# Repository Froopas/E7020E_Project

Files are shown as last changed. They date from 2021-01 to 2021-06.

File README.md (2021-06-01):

# Project Armory
by Josef Utbult (josutb-7@student.ltu.se) and Anton Johansson (anojoh-7@student.ltu.se)

# Specification
We plan to make a mouse wired mouse of our own design with 2 buttons(left and right), a sensor 
instead of a scroll wheel, a 7 segment display to view your progress and a RGB led strip to give 
you the gaming feeling.

## Parts
To make this we would need:
- A PWM3389DM-T3QU sensor ([datasheet](https://www.pixart.com/products-detail/4/PMW3389DM-T3QU))
- A [STM32F411RE](https://www.st.com/en/microcontrollers-microprocessors/stm32f411re.html#overview) MCU ([Reference Manual](https://www.st.com/resource/en/reference_manual/dm00119316-stm32f411xce-advanced-armbased-32bit-mcus-stmicroelectronics.pdf))
- A 3 digit [7 segment display](https://www.elfa.se/en/segment-led-display-mm-red-tht-everlight-electronics-elt315surwa-s530-a3/p/11068625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) ([datasheet](https://www.elfa.se/Web/Downloads/_t/ds/ELT315SURWA-S530-A3_eng_tds.pdf))
- A [LED strip](https://www.elfa.se/en/ws2812b-led-strip-rgb-5v-18w-1m-seeed-studio-104990014/p/30089752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) ([datasheet](https://www.elfa.se/Web/Downloads/_t/ds/WS2812B_104990014_eng_tds.pdf))
- A [Resistive Linear Sensor](https://www.digikey.com/en/products/detail/spectra-symbol/SP-L-0012-103-1--RH/2175422) ([datasheet](https://media.digikey.com/pdf/Data%20Sheets/Spectra%20Symbol/SP%20Series%20SoftPot.pdf))

## Overall design
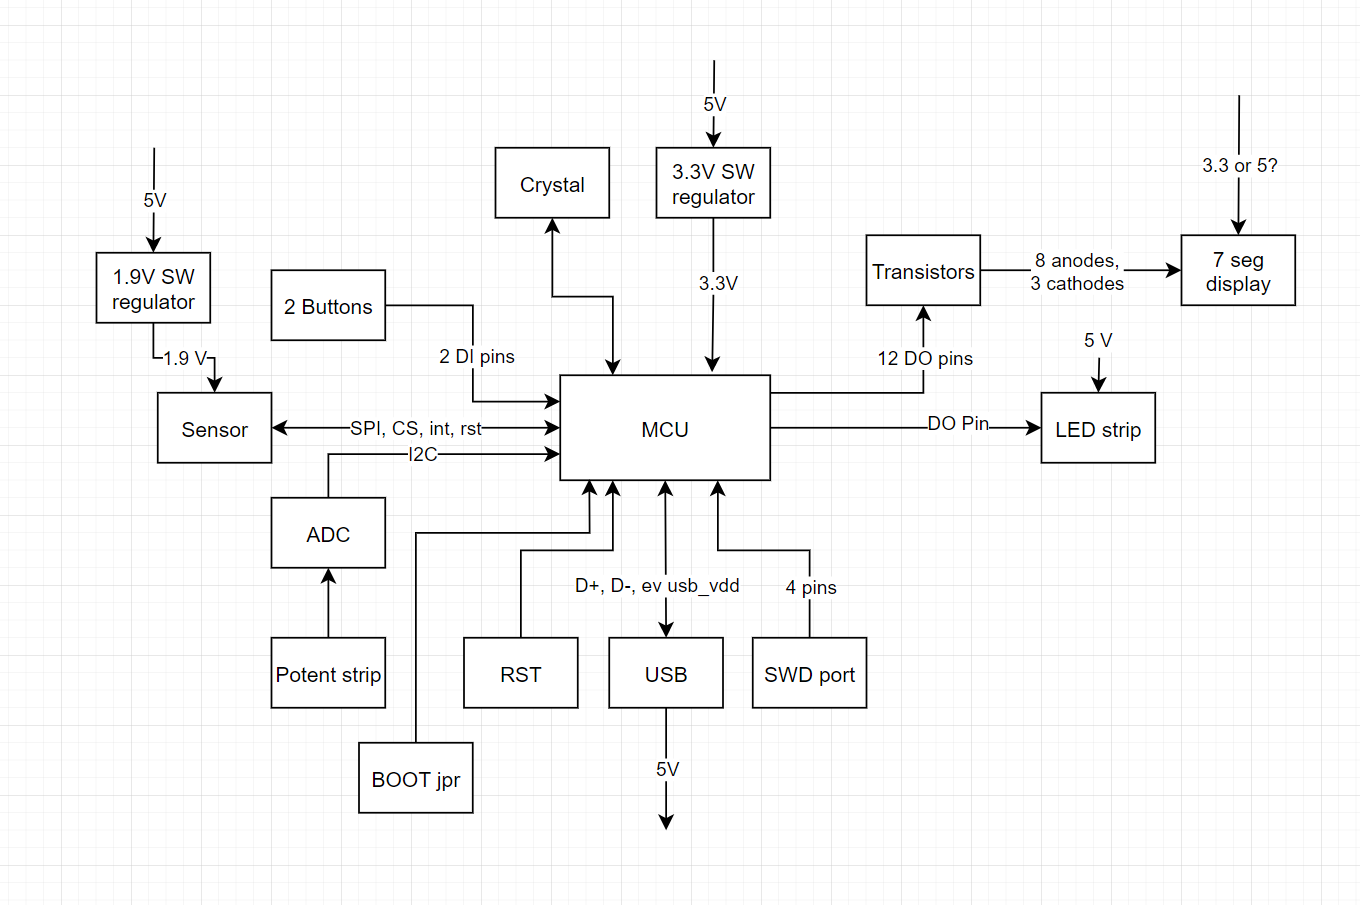
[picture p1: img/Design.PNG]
design Design


## PCB
The PCB is a standard two layer pcb, with the dimentions 40x60 mm.

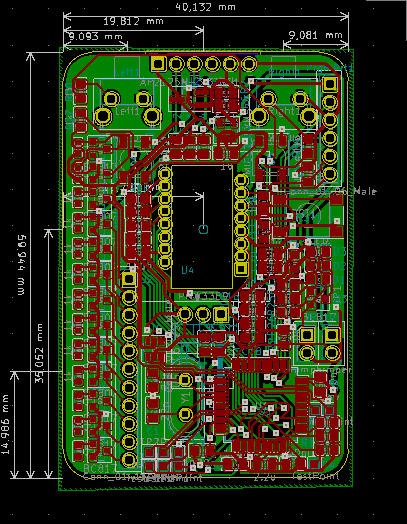
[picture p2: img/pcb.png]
pcb


## Shell
The shell is, at the moment, a 3d render from Fusion 360. It has space for the PCB in the middle 
and some plexi-glass windows to make it more visually pleasing. The buttons on the pcb are 
designed as *vertical* buttons, which means that the mecanic force from the button will have to 
come from the front of the pcb, rather than the top. This enables us to have a shell that is a 
single piece, where some cutout allows the buttons to flex and pivot around where they are joined 
to the rest of the body. The touch strip is placed under the buttons in the middle, and are mounted 
on a seperate piece that is screwed into the rest of the shell.

Shell stuff

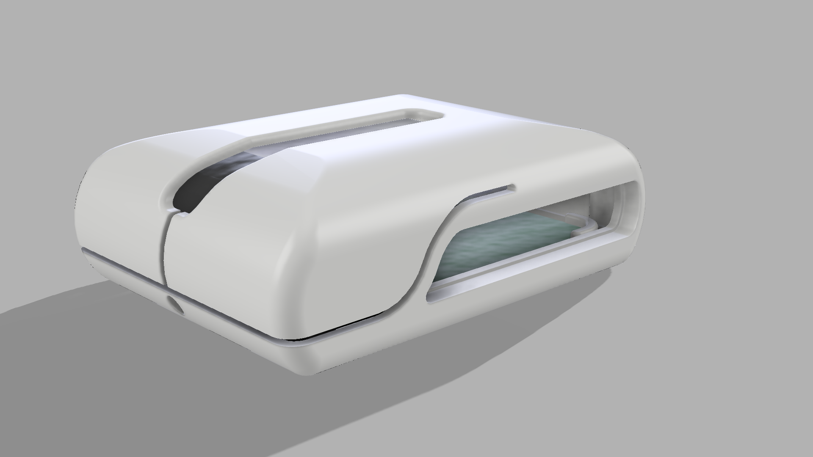
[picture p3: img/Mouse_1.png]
Mouse_1


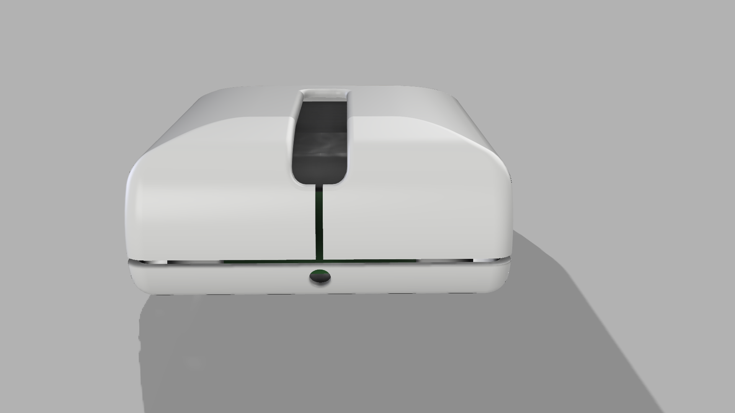
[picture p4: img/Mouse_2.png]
Mouse_2


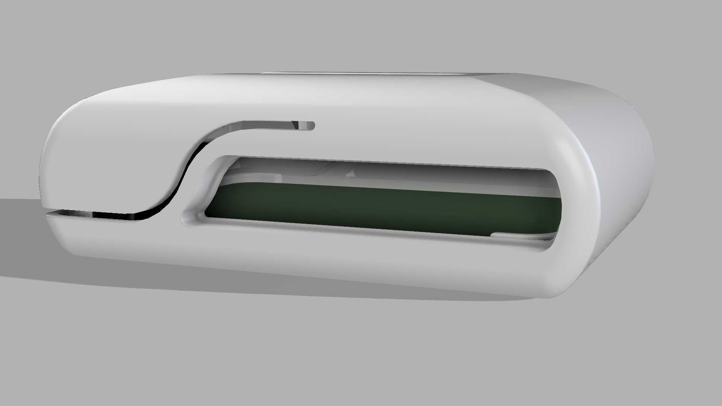
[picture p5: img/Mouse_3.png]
Mouse_3


# Result

As of 26 of March 2021 we have the following result on our project.

## Features

The hardware in place on the mouse is the mcu, the buttons, the PMW sensor and 7 segment 
display. The RGB leds that was supposed to be mounted on the pcb, and the touch sensor was left 
unmounted due to lack of time.

In software we were able to implement RTIC and got the mouse sensor, and the buttons to work with the 
HID protocol. Due to a mismatch in pin selection for the touch strip, the analog pin we chose to connect
the sensor to wasn't compatible with the HAL, which meant we could not get the ADC to work on that pin. 
Therefore, we chose to prioritize other tasks before the touch sensor. And as the RGB leds weren't in 
place we did not test these either.

The first prototype of the shell could fit the pcb and had the sensor working, but it didn't fit the 
display and was not very responsive for the buttons. A second version of this is on the way, but due to 
time constraints this will not be finished for the presentation.

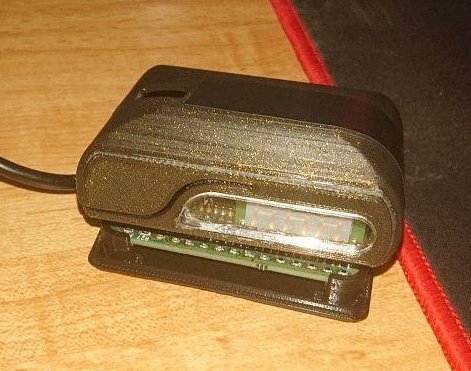
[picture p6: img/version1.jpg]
version1


## Testing

The mouse has been tested on Linux and on Windows. It worked great on Linux, but on Windows we had to 
restart the computer and pull some updates for the mouse to work. The mouse only works on very specific
surfaces, but other than that it is a functional mouse (at best).

## Evaluation

I (Josef) feel that I've could have put in more work on the software side, and less into designing the 
shell. Due to personal problems I had less time to work on it than I would have wanted. 

We feel like we've gotten an acceptable result and that the mouse is good enough for what it is.

## Future goals

We would have liked to implement the following.

* A working touch sensor that supports scrolling and scroll wheel click.

* An ergonomic shell that looks nice and is usable, with easily used mouse buttons.

* Cool led colors.

* Communication from the computer to the mouse to display killcount from CS.

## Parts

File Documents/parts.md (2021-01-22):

# Parts List
## 7 Segment Display
[ELF-511SURWA/S530-A3 - 7](https://www.elfa.se/en/segment-led-display-14-22-mm-red-tht-everlight-electronics-elf-511surwa-s530-a3/p/17506827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) Check how to connect

## Speaker
[KSSG-2308](https://www.elfa.se/en/miniature-loudspeaker-23mm-100mw-8ohm-88db-kingstate-kssg-2308/p/13766343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) Check how to connect

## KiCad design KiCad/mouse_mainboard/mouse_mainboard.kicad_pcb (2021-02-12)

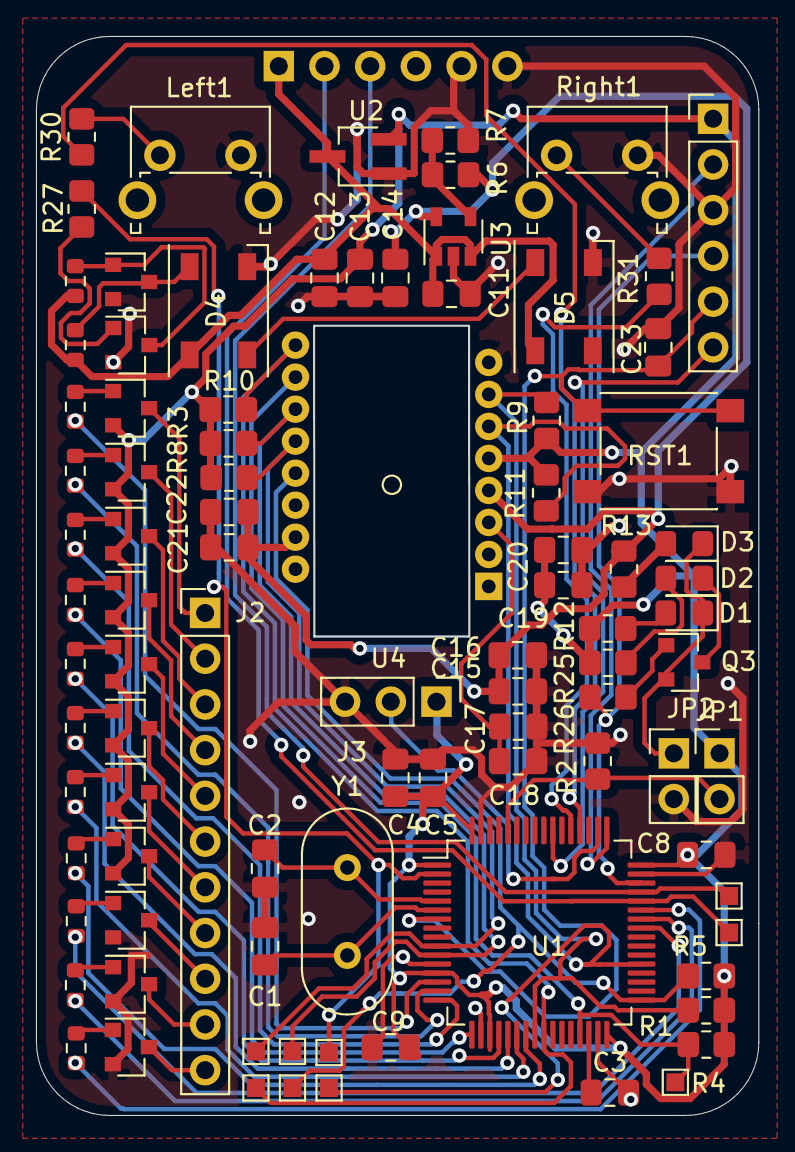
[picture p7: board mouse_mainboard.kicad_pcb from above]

Board: 4 copper layers, 40.1 x 59.9 mm, 93 parts (1 on the bottom side), 72 nets.

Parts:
C1, C2: 47p; C_0805_2012Metric_Pad1.18x1.45mm_HandSolder
C3, C14: 2.2u; C_0805_2012Metric_Pad1.18x1.45mm_HandSolder
C4, C18: 4.7u; C_0805_2012Metric_Pad1.18x1.45mm_HandSolder
C5, C8, C9, C15, C17, C19, C21, C23: 100n; C_0805_2012Metric_Pad1.18x1.45mm_HandSolder
C11, C12, C13: 1u; C_0805_2012Metric_Pad1.18x1.45mm_HandSolder
C16, C20, C22: 10u; C_0805_2012Metric_Pad1.18x1.45mm_HandSolder
D1, D2, D3: LED; LED_0805_2012Metric_Pad1.15x1.40mm_HandSolder
D4, D5: WS2812B; LED_WS2812B_PLCC4_5.0x5.0mm_P3.2mm
J1: USB_OTG; PinHeader_1x06_P2.54mm_Vertical
J2: Conn_01x11_Male; PinHeader_1x11_P2.54mm_Vertical
J3: Conn_01x03_Male; PinHeader_1x03_P2.54mm_Vertical
JP1, JP2: Jumper; PinHeader_1x02_P2.54mm_Vertical
Left1: SW_Push; SW_Tactile_SPST_Angled_PTS645Vx58-2LFS
PrgmPrt1: Conn_01x06_Male; PinHeader_1x06_P2.54mm_Vertical
Q1, Q2, Q4, Q5, Q6, Q8, Q10, Q12: BC807; SOT-23
Q3, Q7, Q9, Q11, Q13, Q14: BC817; SOT-23
R1, R2, R3, R4, R5, R7, R8, R9, R10, R11: 10k; R_0805_2012Metric_Pad1.20x1.40mm_HandSolder
R6: 5.6K; R_0805_2012Metric_Pad1.20x1.40mm_HandSolder
R12, R25: 750R; R_0805_2012Metric_Pad1.20x1.40mm_HandSolder
R13: 50R; R_0805_2012Metric_Pad1.20x1.40mm_HandSolder
R14, R15, R16, R17, R18, R19, R20, R21, R22, R23, R24, R28, R29: 1k; R_0603_1608Metric
R26, R27, R30, R31: 1k; R_0805_2012Metric_Pad1.20x1.40mm_HandSolder
RST1: SW_Push; SW_Push_1P1T_NO_6x6mm_H9.5mm
Right1: SW_Push; SW_Tactile_SPST_Angled_PTS645Vx58-2LFS
TP1, TP2, TP3, TP4, TP5, TP6, TP7, TP8, TP9: TestPoint; TestPoint_Pad_1.0x1.0mm
U1: STM32F411RETx; LQFP-64_10x10mm_P0.5mm
U2: AP2125N-3.3TRG1; SOT-23W_Handsoldering
U3: MIC5235YM5-TR; SOT-23-5
U4: PMW3389; PWM3389DM-T3QU
Y1: Crystal; Crystal_HC49-4H_Vertical

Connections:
+5V: C11.1, C12.1, D4.1, D5.1, J1.1, R28.1, R29.1, U2.3, U3.1, U3.3
GND: C1.2, C2.1, C3.2, C4.2, C5.2, C8.1, C9.1, C11.2, C12.2, C13.2, C14.2, C15.1, C16.1, C17.1, C18.1, C19.1, C20.1, C21.1, C22.1, C23.2, D4.3, D5.3, J1.5, J1.6, J3.3, JP2.2, Left1.2, PrgmPrt1.3, Q7.2, Q9.2, Q11.2, Q13.2, Q14.2, R2.2, R7.1, RST1.2, Right1.2, U1.12, U1.18, U1.31, U1.47, U1.63, U2.1, U3.2, U4.8
unnamed: C1.1, U1.6, Y1.1
unnamed: C2.2, U1.5, Y1.2
unnamed: C3.1, U1.30
unnamed: C17.2, C18.2, U4.3
unnamed: D1.1, D3.1, JP2.1, Q3.2
unnamed: D1.2, R12.2
unnamed: D2.1, Q3.3
unnamed: D2.2, R25.2
unnamed: D3.2, R13.2
unnamed: D4.2, D5.4
unnamed: D4.4, Q14.3, R29.2
unnamed: J2.1, Q12.3
unnamed: J2.2, Q10.3
unnamed: J2.3, Q8.3
unnamed: J2.4, Q6.3
unnamed: J2.5, Q5.3
unnamed: J2.6, Q4.3
unnamed: J2.7, Q2.3
unnamed: J2.8, Q1.3
unnamed: J2.9, Q7.3
unnamed: J2.10, Q9.3
unnamed: J2.11, Q11.3
unnamed: JP1.2, R2.1, U1.60
unnamed: Left1.1, R30.1
unnamed: Q1.1, R24.1
unnamed: Q2.1, R23.1
unnamed: Q3.1, R26.2
unnamed: Q4.1, R22.1
unnamed: Q5.1, R20.1
unnamed: Q6.1, R18.1
unnamed: Q7.1, R17.2
unnamed: Q8.1, R16.1
unnamed: Q9.1, R19.2
unnamed: Q10.1, R15.1
unnamed: Q11.1, R21.2
unnamed: Q12.1, R14.1
unnamed: Q13.1, R27.2
unnamed: Q13.3, Q14.1, R28.2
unnamed: R6.1, R7.2, U3.4
unnamed: R31.1, Right1.1
VDD: C14.1, C15.2, C16.2, C21.2, C22.2, R6.2, R13.1, U3.5, U4.4, U4.15
btn_l: R30.2, U1.52
btn_r: R31.2, U1.53
disp_1: R14.2, U1.14
disp_2: R15.2, U1.15
disp_3: R16.2, U1.16
disp_4: R18.2, U1.17
disp_5: R20.2, U1.20
disp_6: R22.2, U1.21
disp_7: R23.2, U1.22
disp_8: R24.2, U1.23
disp_d1: R17.1, U1.41
disp_d2: R19.1, U1.42
disp_d3: R21.1, U1.43
led_d: R27.1, TP5.1, U1.2
mcu_cap: C4.1, C5.1, C8.2, C9.2, C13.1, C19.2, C20.2, J3.1, JP1.1, PrgmPrt1.1, Q1.2, Q2.2, Q4.2, Q5.2, Q6.2, Q8.2, Q10.2, Q12.2, R1.1, R3.1, R4.1, R5.1, R8.2, R9.2, R10.2, R11.2, R12.1, R25.1, U1.1, U1.13, U1.19, U1.32, U1.48, U1.64, U2.2, U4.5
miso: R8.1, TP2.1, U1.10, U4.12
mosi: R3.2, TP1.1, U1.11, U4.11
ncs: R5.2, TP9.1, U1.33, U4.13
pwm_gpo: R11.1, TP4.1, U1.37, U4.6
pwm_int: R10.1, TP3.1, U1.25, U4.9
pwm_rst: R1.2, R9.1, U1.24, U4.7
sclk: R4.2, TP8.1, U1.29, U4.10
strip_out: J3.2, U1.50
sw_clk: PrgmPrt1.2, U1.49
sw_io: PrgmPrt1.4, R26.1, U1.46
sw_o: PrgmPrt1.6, U1.55
sw_rst: C23.1, PrgmPrt1.5, RST1.1, U1.7
usb_d+: J1.3, TP7.1, U1.45
usb_d-: J1.2, TP6.1, U1.44

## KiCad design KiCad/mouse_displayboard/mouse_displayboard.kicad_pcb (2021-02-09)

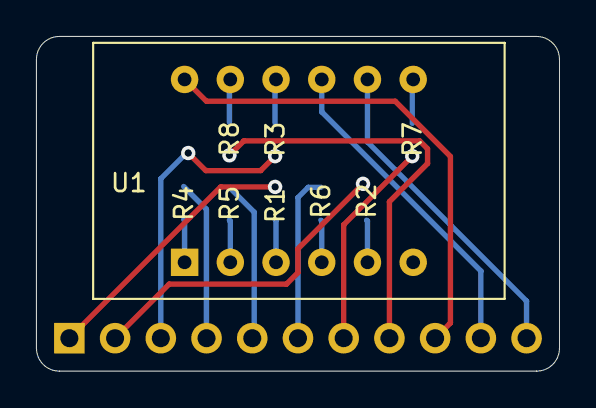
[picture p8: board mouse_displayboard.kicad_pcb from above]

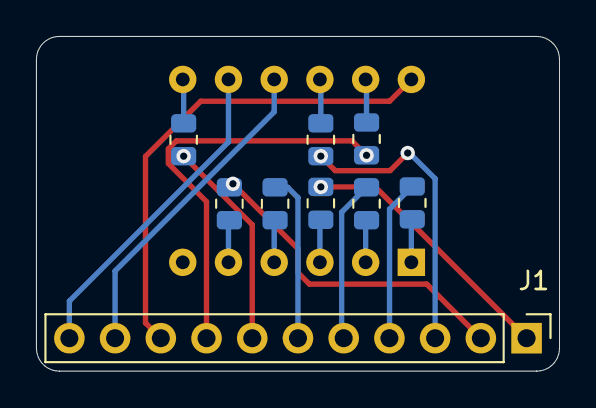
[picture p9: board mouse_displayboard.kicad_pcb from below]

Board: 2 copper layers, 29.1 x 18.6 mm, 10 parts (9 on the bottom side), 19 nets.

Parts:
J1: Conn_01x11_Male; PinHeader_1x11_P2.54mm_Vertical
R1, R2, R3, R4, R5, R6, R7, R8: 220R; R_0805_2012Metric
U1: 7_Segment_Display_3_char; 7 Segment Display 3 char

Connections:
unnamed: J1.1, R1.1
unnamed: J1.2, R2.1
unnamed: J1.3, R3.1
unnamed: J1.4, R4.1
unnamed: J1.5, R5.1
unnamed: J1.6, R6.1
unnamed: J1.7, R7.1
unnamed: J1.8, R8.1
unnamed: J1.9, U1.12
unnamed: J1.10, U1.9
unnamed: J1.11, U1.8
a: R8.2, U1.11
b: R7.2, U1.7
c: R6.2, U1.4
d: R5.2, U1.2
dpx: R1.2, U1.3
e: R4.2, U1.1
f: R3.2, U1.10
g: R2.2, U1.5

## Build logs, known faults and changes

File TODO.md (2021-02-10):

# Tasks
- [] 3d print case
- [] Add all components to components list
- [] Produce shopping cart

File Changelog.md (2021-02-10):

# Changes since 2021-02-08
- Changed Crystal to through hole crystal.
- Changed crystal capacitors to correct values for new crystal.

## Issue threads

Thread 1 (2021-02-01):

Wrong footprint for the 3-pins

01joja, 2021-02-01:
I think that you have put in the wrong footprint for the pins. It will not have any impact in the end product but it look funny in the 3D module.

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

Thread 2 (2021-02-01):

Crystal

01joja, 2021-02-01:
The [crystal](https://www.elfa.se/sv/kristall-ytmontering-16mhz-iqd-lfxtal029370/p/30131284) specified in the lab has this solder pad layout
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

If you are using anything different I think its best that you specify that and (if needed) change the capacitors.

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

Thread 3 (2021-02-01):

Lab 2  Peer-Review

alesun-6, 2021-02-01:
Jag måste bara börja med att säga att din PCB ser väldigt bra ut. Jag kunde bara hitta två saker som jag skulle kunna tro är fel eller något liknade. Det är en komponent (J3)  som över lapar med din kristall i 3D mode. Samt så ser det ut som du har några varningar (courtyard overlaps) som skulle kunna fixas.

Annars så ser det ut som du har hoppat över att följa instruktionerna på några delar t.ex. över copper layer och skapa power net class, men allt det ser medvetet ut. Jag tror du har mycket bättre koll på det här än mig, så jag vill bara påpeka det så du vet.

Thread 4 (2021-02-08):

Project Peer-Review

alesun-6, 2021-02-08:
- Det finns ingen changelog eller TODO list i projekt mappen.
- Ni har ganska många varningar om man gör en ERC.
- Ett av ERC varningarna kan ni fixa om du sätter om pin 3 på PMW3389 till power output.

Det gick inte att öppna footprint, vet inte om det var ett bug på vår sida eller något så vi kunde inte kolla det. Men annars såg allt bra ut.

JosefUtbult, 2021-02-09:
Bra poäng med pinnen på PMW3389an. Det löser vi. ERC checkarna har jag koll på. Det är några som beror på minimala overlaps, till följd av ett underligt grid, men det ska vara lugnt. En är pga en header som går igenom kristallen, men denne går att löda högre upp för att ge lite clearing. Footprintsen är lite problematiskt fortfarande. Vi fick en bug som satte alla footprints till solder points. Därför är de lite svårt att öppna för tillfället. Tack för kritiken.

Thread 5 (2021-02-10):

Project PCB Review

alesun-6, 2021-02-10:
- Kristallen som användes på labben och som skolan kommer att beställa är smd, tänkte bara påpeka om ni ska använda den
- Om det är möjligt skulle det vara bättre med kortare routes på det undre coppar layer
- Skulle också vara bra om d+ och d- hade kortare sträcka till MCU

Vet inte hur mycket av det har som går att fixa på er design, det är ganska trångt redan. Samt vet vi inte om ni ska beställa egen kristall eller inte men hoppas att review:n hjälper något.

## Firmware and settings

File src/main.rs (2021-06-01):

// > cargo run usb-mouse
// or
// > cargo run usb-mouse --release

#![no_main]
#![no_std]

use stm32f4xx_hal::{
    dwt::Dwt,
    gpio::{
        gpioa::{PA0,PA1,PA2,PA3,PA4,PA5,PA6,PA7,PA8, PA9, PA10},
        gpiob::{PB10, PB4, PB12, PB0},
        gpioc::{PC13, PC2, PC3, PC11, PC12},
        Input,
        PullUp,
        Analog,
        Alternate, Output, PushPull, Speed,
    },
    otg_fs::{UsbBus, UsbBusType, USB},
    spi::Spi,
    prelude::*,
    stm32::ADC1,
    adc::{
        Adc,
        config::AdcConfig,
        config::SampleTime,
        config::Sequence,
        config::Eoc,
        config::Scan,
        config::Clock,
        Temperature,
    },
};
use embedded_hal::spi::MODE_3;
use cortex_m::{asm::delay, peripheral::DWT};
use usb_device::{bus::UsbBusAllocator, prelude::*};
use usbd_hid::{
    descriptor::{generator_prelude::*, MouseReport},
    hid_class::HIDClass,
};

use panic_rtt_target as _;
use rtt_target::{rprintln, rtt_init_print};

use rtic::{cyccnt::{Instant, U32Ext as _}, export::Priority};

use app::{
    pmw3389::{self, Register},
    DwtDelay,
};

type PMW3389T = pmw3389::Pmw3389<
    Spi<
        stm32f4xx_hal::stm32::SPI2,
        (
            PB10<Alternate<stm32f4xx_hal::gpio::AF5>>,
            PC2<Alternate<stm32f4xx_hal::gpio::AF5>>,
            PC3<Alternate<stm32f4xx_hal::gpio::AF5>>,
        ),
    >,
    PB12<Output<PushPull>>,
>;

pub struct SevenSegmentDisplay {
    segDP: PA0<Output<PushPull>>,
    segG: PA1<Output<PushPull>>,
    segF: PA2<Output<PushPull>>,
    segE: PA3<Output<PushPull>>,
    segD: PA4<Output<PushPull>>,
    segC: PA5<Output<PushPull>>,
    segB: PA6<Output<PushPull>>,
    segA: PA7<Output<PushPull>>,
    dig1: u8,
    dig2: u8,
    dig3: u8
}

pub struct ACDC {
    adc:Adc<ADC1>,
    pb0:PB0<Analog>
}

const RATIO: u32 = 5;
const ADC_THREASHOLD: i16 = 10;

#[rtic::app(device = stm32f4xx_hal::stm32, monotonic = rtic::cyccnt::CYCCNT, peripherals = true)]
const APP: () = {
    struct Resources {
        pmw3389: PMW3389T,
        hid: HIDClass<'static, UsbBusType>,
        usb_dev: UsbDevice<'static, UsbBus<USB>>,
        
        r_buttn: PC12<Input<PullUp>>,
        l_buttn: PC11<Input<PullUp>>,

        #[init(0)]
        x_cord: i8,
        #[init(0)]
        y_cord: i8,

        disp1: SevenSegmentDisplay,
        dispi1: PA8<Output<PushPull>>,
        dispi2: PA9<Output<PushPull>>,
        dispi3: PA10<Output<PushPull>>,

        adc_struct: ACDC,

        #[init(0)]
        adc_temperature_last_val: u16,
        #[init(0)]
        adc_scroll_last_val: u16,
    }

    #[init(schedule=[poll_pmw, display])]
    fn init(ctx: init::Context) -> init::LateResources {
        static mut EP_MEMORY: [u32; 1024] = [0; 1024];
        static mut USB_BUS: Option<UsbBusAllocator<UsbBusType>> = None;

        rtt_init_print!();
        rprintln!("init");
        let mut core = ctx.core;

        core.DCB.enable_trace();
        DWT::unlock();
        core.DWT.enable_cycle_counter();

        // Set up the system clock.
        let rcc = ctx.device.RCC.constrain();
        let _clocks = rcc.cfgr.sysclk(48.mhz()).require_pll48clk().freeze();

        let gpiob = ctx.device.GPIOB.split();

        let gpioc = ctx.device.GPIOC.split();
        let btn = gpioc.pc13.into_pull_up_input();

        let gpioa = ctx.device.GPIOA.split();
        let usb = USB {
            usb_global: ctx.device.OTG_FS_GLOBAL,
            usb_device: ctx.device.OTG_FS_DEVICE,
            usb_pwrclk: ctx.device.OTG_FS_PWRCLK,
            pin_dm: gpioa.pa11.into_alternate_af10(),
            pin_dp: gpioa.pa12.into_alternate_af10(),
        };

        let sck = gpiob.pb10.into_alternate_af5();
        let miso = gpioc.pc2.into_alternate_af5();
        let mosi = gpioc.pc3.into_alternate_af5();
        let cs = gpiob.pb12.into_push_pull_output().set_speed(Speed::High);

        let spi = Spi::spi2(
            ctx.device.SPI2,
            (sck, miso, mosi),
            MODE_3,
            stm32f4xx_hal::time::KiloHertz(2000).into(),
            _clocks,
        );

        let mut delay2 = DwtDelay::new(&mut core.DWT, _clocks);
        let mut pmw3389 = pmw3389::Pmw3389::new(spi, cs, delay2).unwrap();

        // set in burst mode
        pmw3389.write_register(Register::MotionBurst, 0x00);

        // semantically, the monotonic timer is frozen at time "zero" during `init`
        // NOTE do *not* call `Instant::now` in this context; it will return a nonsense value
        let now = ctx.start; // the start time of the system

        ctx.schedule.poll_pmw(now + 16_000.cycles()).unwrap();

        ctx.schedule.display(now + 48_000.cycles()).unwrap();

        USB_BUS.replace(UsbBus::new(usb, EP_MEMORY));

        let hid = HIDClass::new(USB_BUS.as_ref().unwrap(), MouseReport::desc(), 1);
        let usb_dev = UsbDeviceBuilder::new(USB_BUS.as_ref().unwrap(), UsbVidPid(0xc410, 0x0000))
            .manufacturer("Anton och Josef INC")
            .product("Mouse")
            .serial_number("1.0")
            .device_class(0)
            .build();

        let pc11 = gpioc.pc11.into_pull_up_input();
        let pc12 = gpioc.pc12.into_pull_up_input();

        let (
            pa0,
            pa1,
            pa2,
            pa3,
            pa4,
            pa5,
            pa6,
            pa7) = (
            gpioa.pa0.into_push_pull_output(),
            gpioa.pa1.into_push_pull_output(),
            gpioa.pa2.into_push_pull_output(),
            gpioa.pa3.into_push_pull_output(),
            gpioa.pa4.into_push_pull_output(),
            gpioa.pa5.into_push_pull_output(),
            gpioa.pa6.into_push_pull_output(),
            gpioa.pa7.into_push_pull_output(),
        );

        let d1 = SevenSegmentDisplay{
            segDP: pa0,
            segG: pa1,
            segF: pa2,
            segE: pa3,
            segD: pa4,
            segC: pa5,
            segB: pa6,
            segA: pa7,
            dig1: 1,
            dig2: 2,
            dig3: 3,
        };

        let di1 = gpioa.pa8.into_push_pull_output();
        let di2 = gpioa.pa9.into_push_pull_output();
        let di3 = gpioa.pa10.into_push_pull_output();

        let mut adc = Adc::adc1(ctx.device.ADC1, true, AdcConfig::default());
        adc.enable_temperature_and_vref();
        let pb0 = gpiob.pb0.into_analog();
        let adc_struct = ACDC {
            adc:adc,
            pb0:pb0,            
        };

        init::LateResources { pmw3389, hid, usb_dev, r_buttn:pc12, l_buttn:pc11, disp1:d1, dispi1:di1, dispi2:di2, dispi3:di3, adc_struct:adc_struct}
    }

    #[task(priority = 2, resources = [pmw3389, x_cord, y_cord], schedule = [poll_pmw])]
    fn poll_pmw(cx: poll_pmw::Context) {
        let res = cx.resources;

        let (x, y) = res.pmw3389.read_status().unwrap();
        
        let dx = x as i8;
        let dy = y as i8;

        *res.x_cord += dx;
        *res.y_cord += dy;

        cx.schedule
            .poll_pmw(cx.scheduled + (RATIO * 16_000).cycles())
            .unwrap();
    }

    #[task(binds=OTG_FS, resources = [ hid, usb_dev, x_cord, y_cord, r_buttn, l_buttn, adc_temperature_last_val, disp1, adc_scroll_last_val, adc_struct], priority = 2)]
    fn on_usb(mut ctx: on_usb::Context) {
        static mut x_overflow: i8 = 0;
        static mut y_overflow: i8 = 0;
        static DPI:i8 = 10;
        static SCROLL_DIST: i8 = 2;

        let adc_struct = ctx.resources.adc_struct;
        let mut temp_last: u16 = *ctx.resources.adc_temperature_last_val;
        let mut temp_curr: u16 = adc_struct.adc.convert(&Temperature, SampleTime::Cycles_144);
        let mut scroll_last: u16 = *ctx.resources.adc_scroll_last_val;
        let mut scroll_curr: u16 = adc_struct.adc.convert(&adc_struct.pb0, SampleTime::Cycles_144);;

        let scroll_diff = scroll_curr as i16 - scroll_last as i16;

        let temp_diff = (temp_curr as i16 - temp_last as i16).abs();

        if temp_diff > ADC_THREASHOLD {
            let disp = ctx.resources.disp1;
            let temp = ((temp_curr as f32) * 0.62 ) - 549.5;
            let temp2: u32 = temp as u32;
            disp.dig1 = (temp2 as u8/100)%10;
            disp.dig2 = (temp2 as u8/10)%10;
            disp.dig3 = (temp2 as u8)%10;
            *ctx.resources.adc_temperature_last_val = temp_curr;
        }
        let mut scroll_output:i8 = 0;
        if scroll_diff.abs() > 100 && scroll_curr > 300 {
            *ctx.resources.adc_scroll_last_val = scroll_curr;
            if (scroll_diff > 0) {
                scroll_output = SCROLL_DIST;
            } else {
                scroll_output = -SCROLL_DIST;
            }
        }

        // destruct the context
        let (usb_dev,
            hid,
            x_cord,
            y_cord,
            r_buttn,
            l_buttn,
        ) = ( 
            ctx.resources.usb_dev, 
            ctx.resources.hid,
            ctx.resources.x_cord,
            ctx.resources.y_cord,
            ctx.resources.r_buttn,
            ctx.resources.l_buttn,
        );

        let x = (*x_cord + *x_overflow) / DPI;
        *x_overflow = (*x_cord + *x_overflow) % DPI;

        let y = (*y_cord + *y_overflow) / DPI;
        *y_overflow = (*y_cord + *y_overflow) % DPI;


        let report = MouseReport {
            x: x,
            y: y,
            buttons: ((r_buttn.is_low().unwrap() as u8 )<< 1) | (l_buttn.is_low().unwrap() as u8), // (into takes a bool into an integer)
            wheel: scroll_output,
        };

        *x_cord = 0;
        *y_cord = 0;
        // push the report
        hid.push_input(&report).ok();

        // update the usb device state
        if usb_dev.poll(&mut [hid]) {
            return;
        }
    }

    #[task(resources=[disp1,dispi1,dispi2,dispi3], schedule=[display], priority = 2)]
    fn display(mut cx: display::Context) {
        static mut DISP:u8 = 0;
        cx.schedule.display(cx.scheduled + (5 * 48_000).cycles()).unwrap();
        let disp:  &mut SevenSegmentDisplay = cx.resources.disp1;
        match DISP {
            0 => {
                cx.resources.dispi1.set_high().ok();
                cx.resources.dispi2.set_low().ok();
                cx.resources.dispi3.set_low().ok();
                print_segment(disp, disp.dig1);
            },
            1 => {
                cx.resources.dispi1.set_low().ok();
                cx.resources.dispi2.set_high().ok();
                cx.resources.dispi3.set_low().ok();
                print_segment(disp, disp.dig2);
            }
            2 => {
                cx.resources.dispi1.set_low().ok();
                cx.resources.dispi2.set_low().ok();
                cx.resources.dispi3.set_high().ok();
                print_segment(disp, disp.dig3);
            }
            _ => {
            }
        }
        *DISP = (*DISP+1)%3;
    }

    #[idle]
    fn idle(cx: idle::Context) -> ! {
        rprintln!("idle");
        loop {
            continue;
        }
    }


    extern "C" {
        fn EXTI0();
        fn EXTI1();
        fn EXTI2();
    }
};

fn print_segment(disp: &mut SevenSegmentDisplay, digit:u8) {
    disp.segDP.set_high().ok();
    disp.segG.set_high().ok();
    disp.segF.set_high().ok();
    disp.segE.set_high().ok();
    disp.segD.set_high().ok();
    disp.segC.set_high().ok();
    disp.segB.set_high().ok();
    disp.segA.set_high().ok();
    match digit {
        1 => {
            disp.segB.set_low().ok();
            disp.segC.set_low().ok();
            //rprintln!("printing 1");
        },
        2 => {
            disp.segA.set_low().ok();
            disp.segB.set_low().ok();
            disp.segG.set_low().ok();
            disp.segE.set_low().ok();
            disp.segD.set_low().ok();
        }
        3 => {
            disp.segA.set_low().ok();
            disp.segB.set_low().ok();
            disp.segG.set_low().ok();
            disp.segC.set_low().ok();
            disp.segD.set_low().ok();
        }
        4 => {
            disp.segF.set_low().ok();
            disp.segB.set_low().ok();
            disp.segG.set_low().ok();
            disp.segC.set_low().ok();
        }
        5 => {
            disp.segA.set_low().ok();
            disp.segF.set_low().ok();
            disp.segG.set_low().ok();
            disp.segC.set_low().ok();
            disp.segD.set_low().ok();
        }
        6 => {
            disp.segA.set_low().ok();
            disp.segF.set_low().ok();
            disp.segG.set_low().ok();
            disp.segD.set_low().ok();
            disp.segE.set_low().ok();
            disp.segC.set_low().ok();
        }
        7 => {
            disp.segB.set_low().ok();
            disp.segC.set_low().ok();
            disp.segA.set_low().ok();
        }
        8 => {
            disp.segA.set_low().ok();
            disp.segB.set_low().ok();
            disp.segF.set_low().ok();
            disp.segG.set_low().ok();
            disp.segD.set_low().ok();
            disp.segE.set_low().ok();
            disp.segC.set_low().ok();
        }
        9 => {
            disp.segA.set_low().ok();
            disp.segB.set_low().ok();
            disp.segF.set_low().ok();
            disp.segG.set_low().ok();
            disp.segD.set_low().ok();
            disp.segC.set_low().ok();
        }
        0 => {
            disp.segA.set_low().ok();
            disp.segB.set_low().ok();
            disp.segF.set_low().ok();
            disp.segD.set_low().ok();
            disp.segE.set_low().ok();
            disp.segC.set_low().ok();
        }
        _ => {

        }
    }

}

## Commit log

2021-01-19 Init kicad files and some notes
    [mouse_mainboard.kicad_pcb, mouse_mainboard.sch]
2021-01-22 Added initial components and created a display board
    [MCU.sch, display_and_indicators.sch, mouse_displayboard.kicad_pcb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]
2021-01-26 Init layout and fixed wiring
    [MCU.sch, display_and_indicators.sch, mouse_mainboard.kicad_pcb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]
2021-01-26 Added test points
    [MCU.sch, mouse_mainboard.kicad_pcb, ports.sch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]
2021-01-28 Added pot strip port
    [MCU.sch, mouse_mainboard.kicad_pcb, user_interface.sch]
2021-01-29 Add picture of pcb
2021-02-01 Changed display board and created a new component
    [mouse_displayboard.kicad_pcb, mouse_displayboard.sch, user_interface.sch]
2021-02-05 Add layer, fixed references and added logo
    [mouse_mainboard.kicad_pcb]
2021-02-09 Added resistors for display-board
    [MCU.sch, mouse_displayboard.kicad_pcb, mouse_displayboard.sch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]
2021-02-12 Connected display
    [MCU.sch, mouse_mainboard.kicad_pcb, power_regulators.sch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]
2021-02-12 Fixed footprints
    [MCU.sch, mouse_mainboard.kicad_pcb, ports.sch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]
2021-03-18 button and sensor movement works
2021-03-26 Added temperature analog reading
2021-03-26 Add temperature reading
2021-06-01 Added comment for linear temperature function
